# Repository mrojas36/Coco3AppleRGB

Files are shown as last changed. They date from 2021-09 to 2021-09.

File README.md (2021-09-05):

# Coco3AppleRGB

This card will interface the **Color Computer 3 RGB port** to an **AppleColor RGB Monitor (model A2M6014)**.  It was created and shared with the CoCo community.  The design is provided here for whatever purpose you would like: make for yourself, build, sell, or modify.

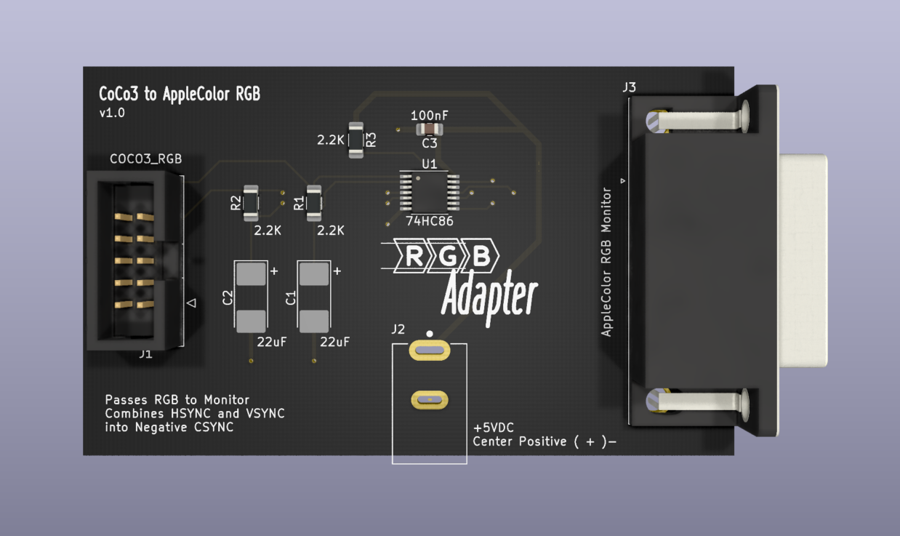
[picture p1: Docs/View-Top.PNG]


## Overview

The card was designed from an schematic from 1996 by Tomi Engdahl.  The circuit was modified to work with the AppleColor RGB Monitor. Here is the original schematic:

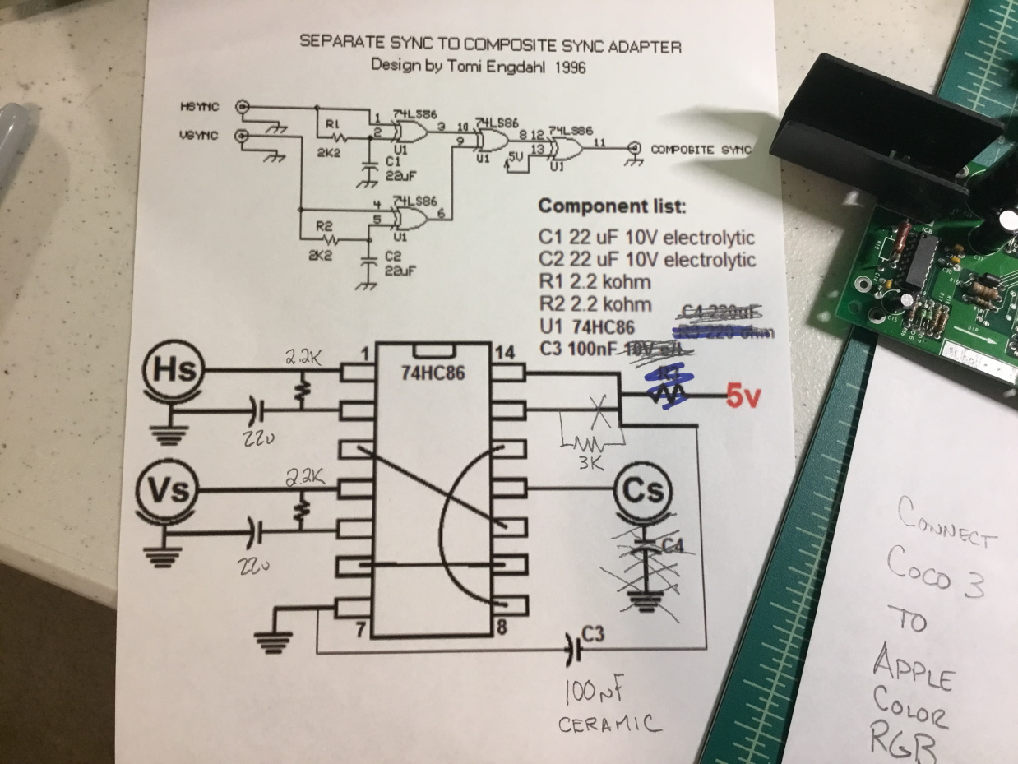
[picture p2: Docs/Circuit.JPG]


I bread boarded this circuit and made modifications (shown in pencil) to get it to work with the Apple Monitor. 

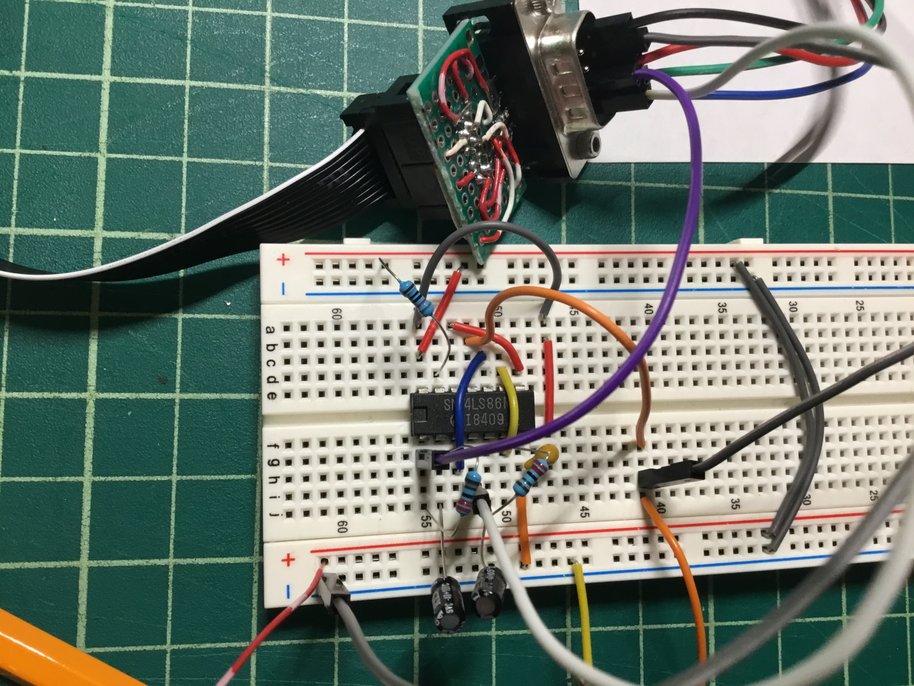
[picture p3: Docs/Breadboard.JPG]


With a bit of fiddling, I was able to achieve a display:

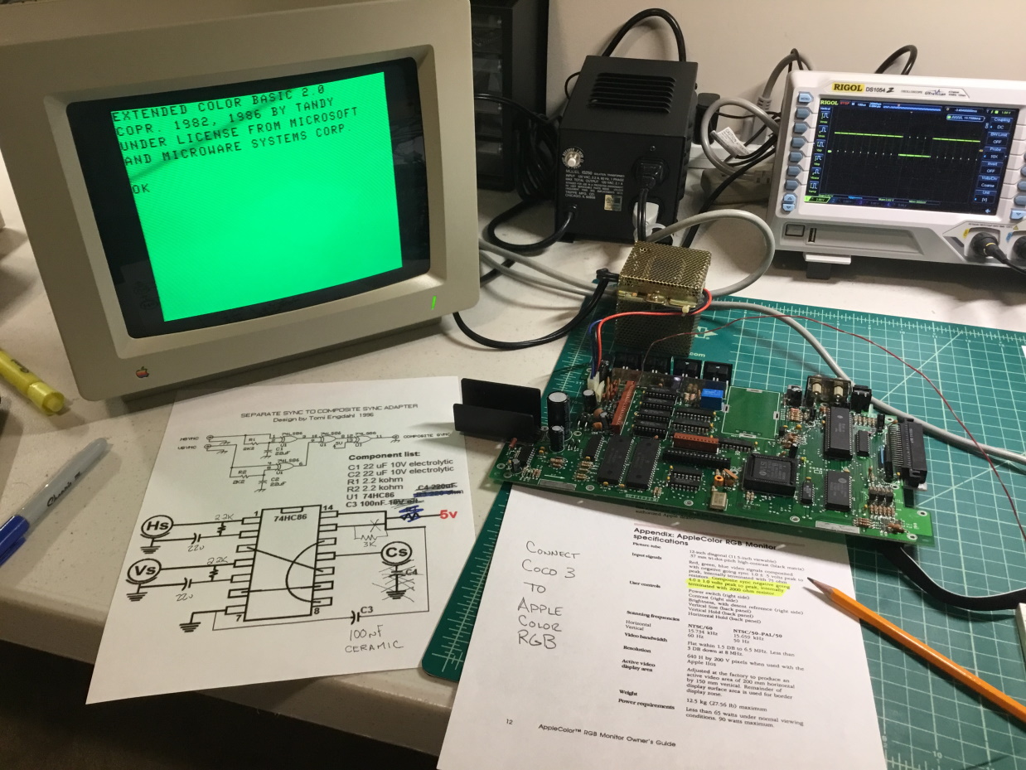
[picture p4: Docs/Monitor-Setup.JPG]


The key to getting this to work was recognizing that the Apple Monitor needs a *composite* sync (CSYNC) in order to display.  The CoCo3 has separate horizontal and vertical sync signals.  This circuit will take those signals, flip them, and then interface them into a composite signal (show on the oscilloscope).  Here is the resulting schematic:

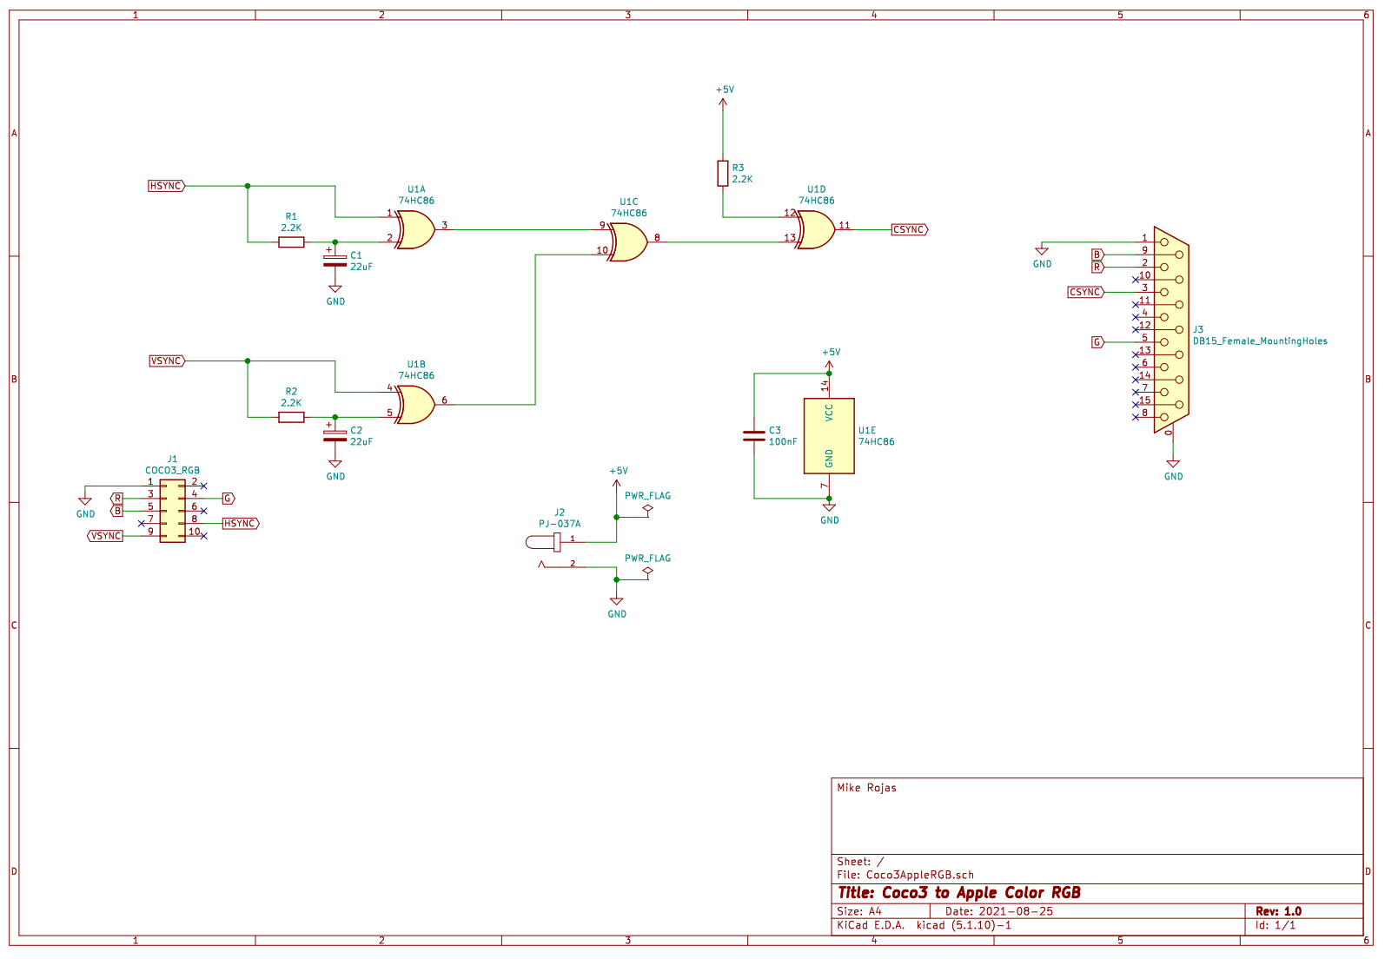
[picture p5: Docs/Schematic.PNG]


## Design

The project was built in **Kicad** and has all the project files included.  You can get a copy of Kicad from https://www.kicad.org.

Kicad was also used to layout of the PCB, show here:

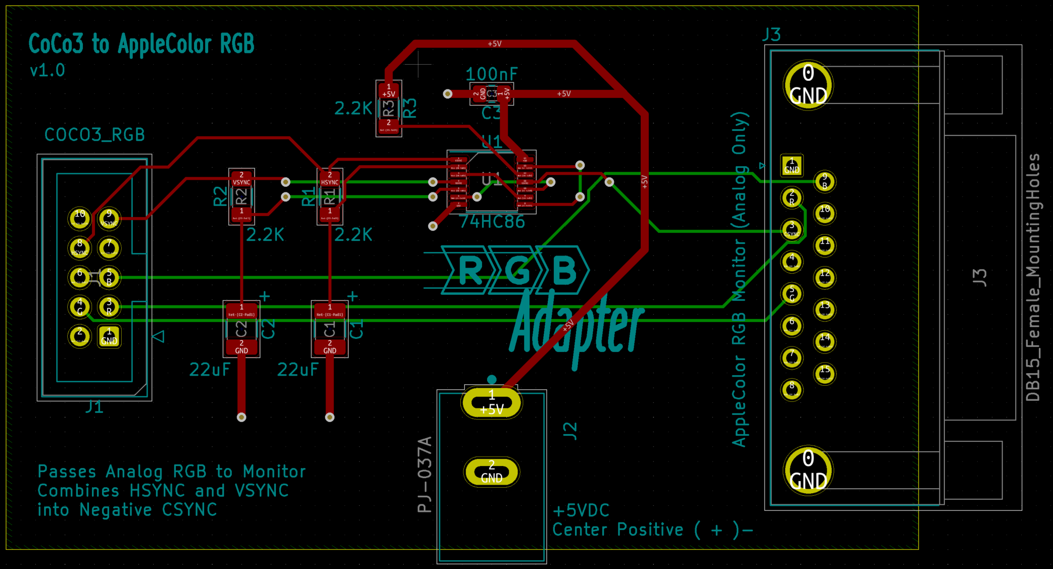
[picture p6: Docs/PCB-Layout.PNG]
PCB Layout


The bill of material is straightforward and only contains easy to find parts.  At the time of writing the total board cost is under $7 USD.

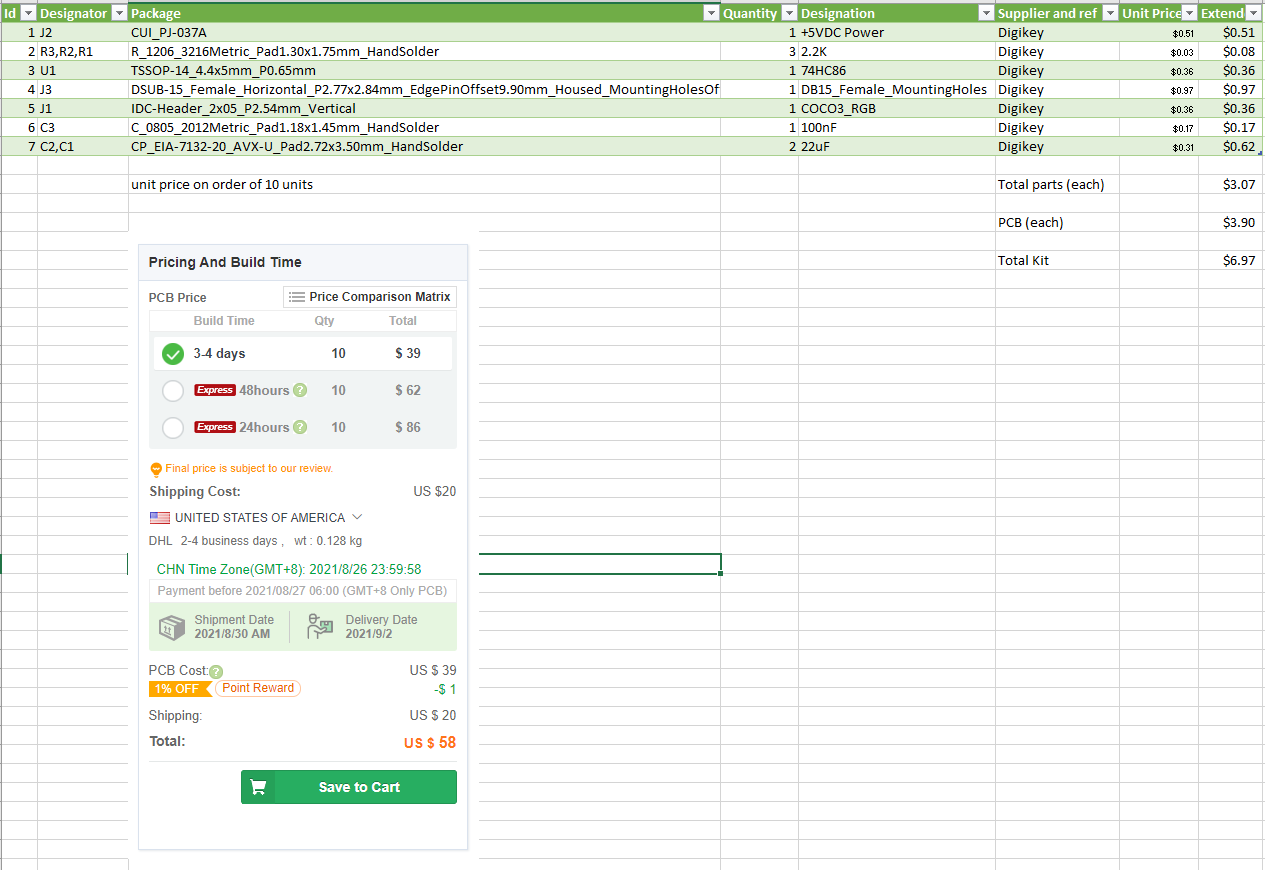
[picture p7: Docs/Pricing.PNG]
Pricing


The finished board:

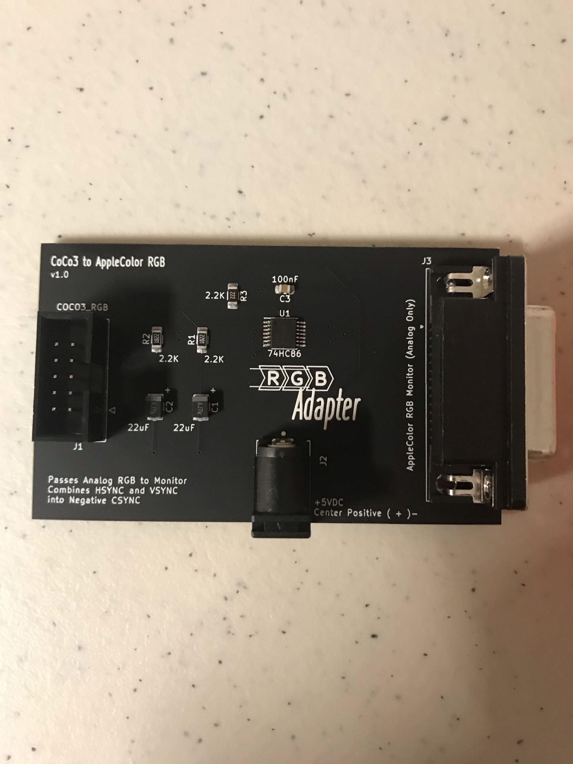
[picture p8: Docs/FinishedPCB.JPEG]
PCB


## Case

This project also contains a 3D printable case design.  The case is in two parts: Top and Bottom.  No screws are needed as the bottom slides into the top part for a snug fit.

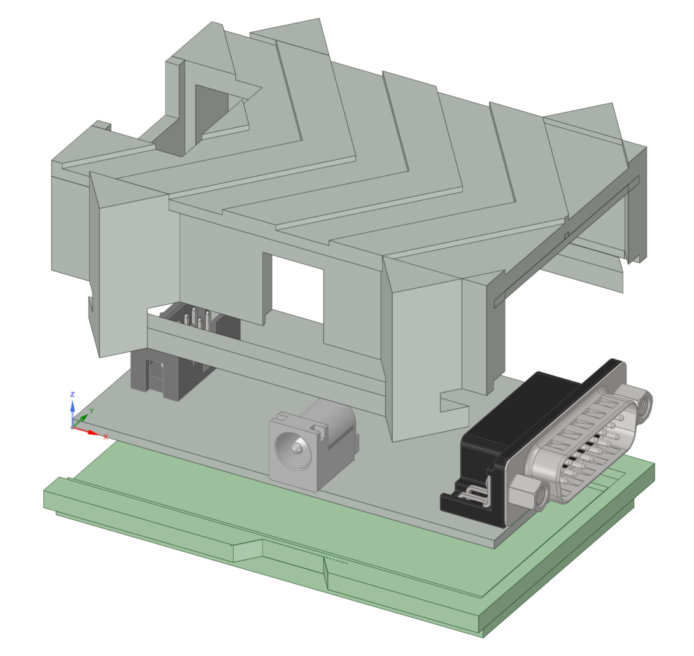
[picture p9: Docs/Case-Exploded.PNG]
Case


The case was designed using **DesignSpark Mechanical**.  This is a free design tool.  You can download the tool from https://www.rs-online.com/designspark/mechanical-software.  The design files are included in the Case folder.

Here are some photos of the finished case:

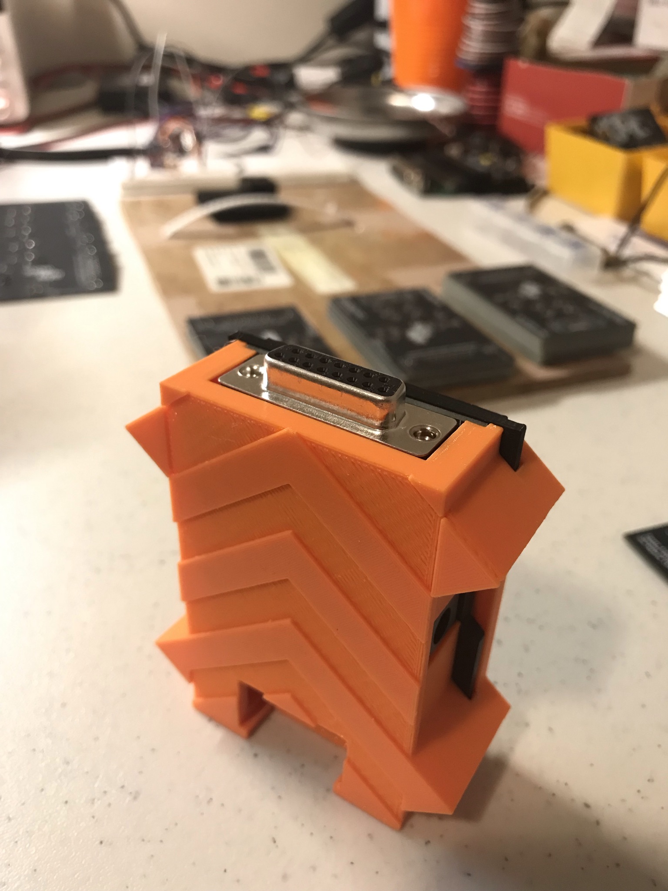
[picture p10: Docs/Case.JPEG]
Case

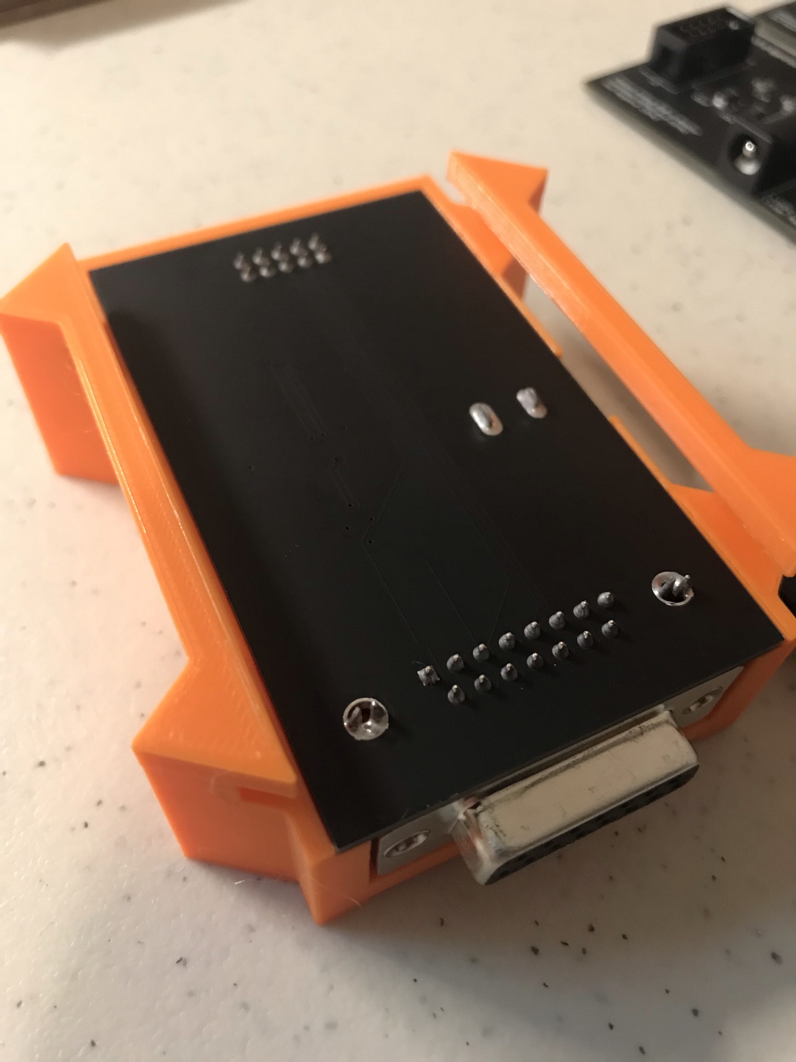
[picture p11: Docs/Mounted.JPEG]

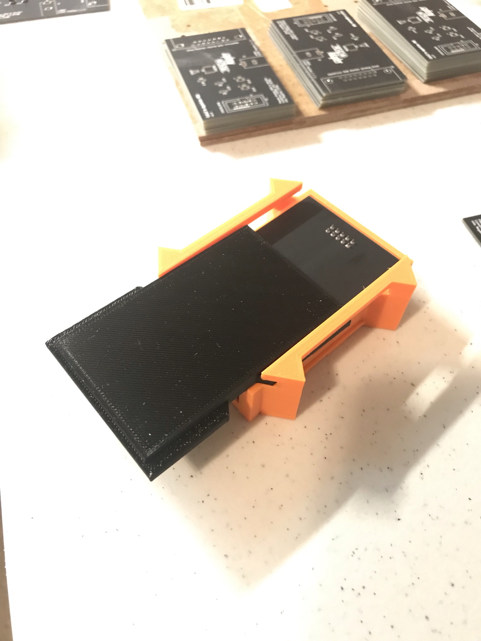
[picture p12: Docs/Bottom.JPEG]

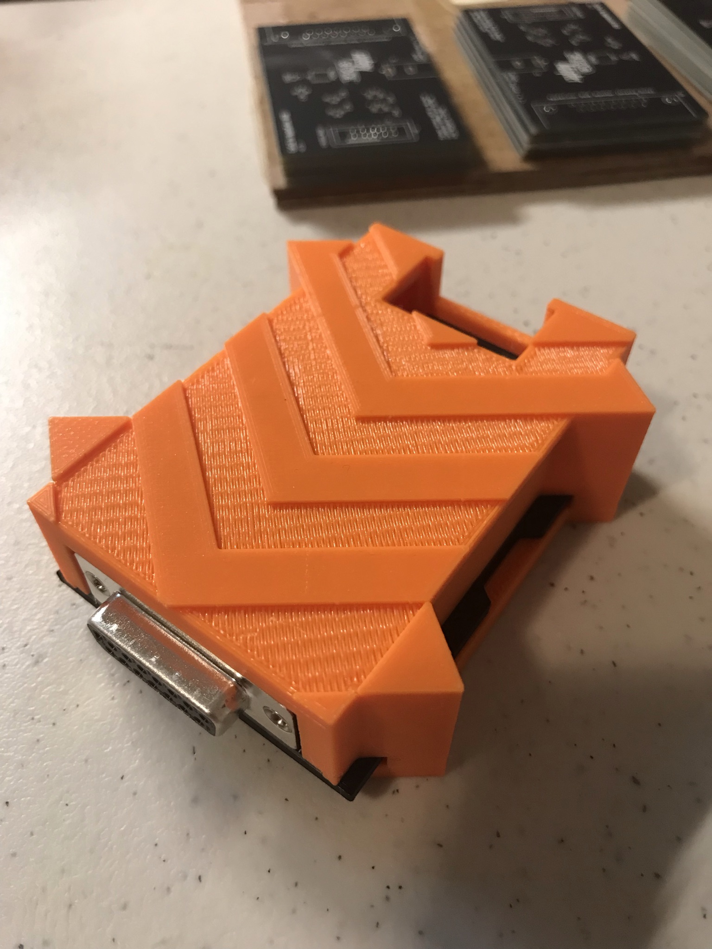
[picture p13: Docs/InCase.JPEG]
Case


## Additional Parts

The adapter works very well and 80 column text is very legible. To complete the set you will need a **5VDC Power Adaptor with a 5.5mm x 2.5mm plug, center positive**.  You will also need a **10 pin ribbon cable** to connect to the underside of the CoCo3.

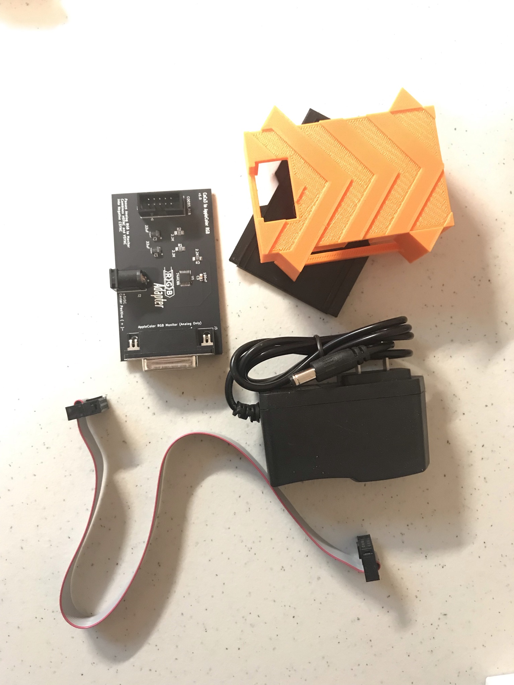
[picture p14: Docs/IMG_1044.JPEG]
Set

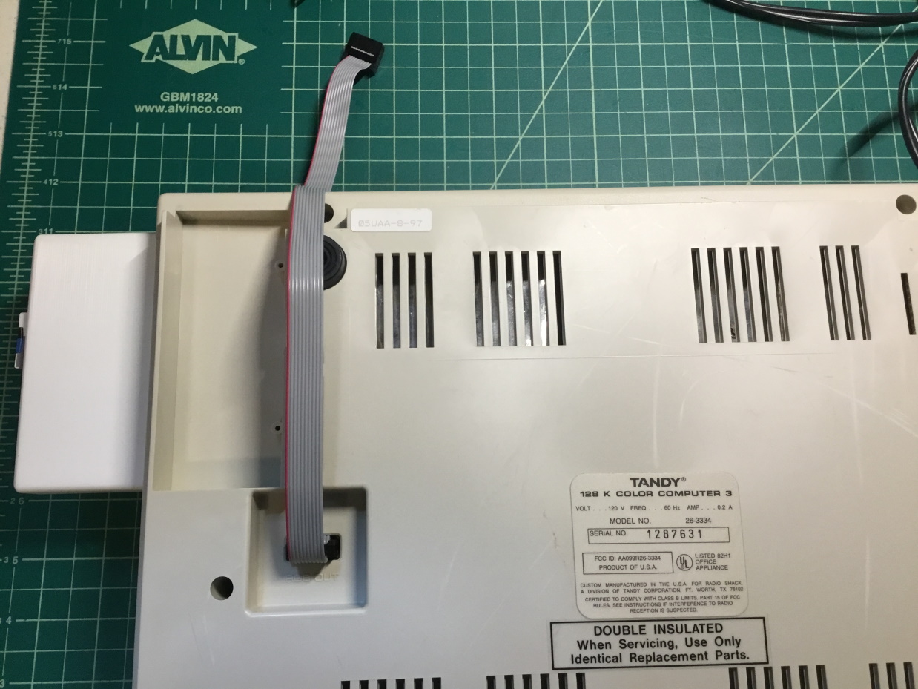
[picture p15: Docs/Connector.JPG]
Connector

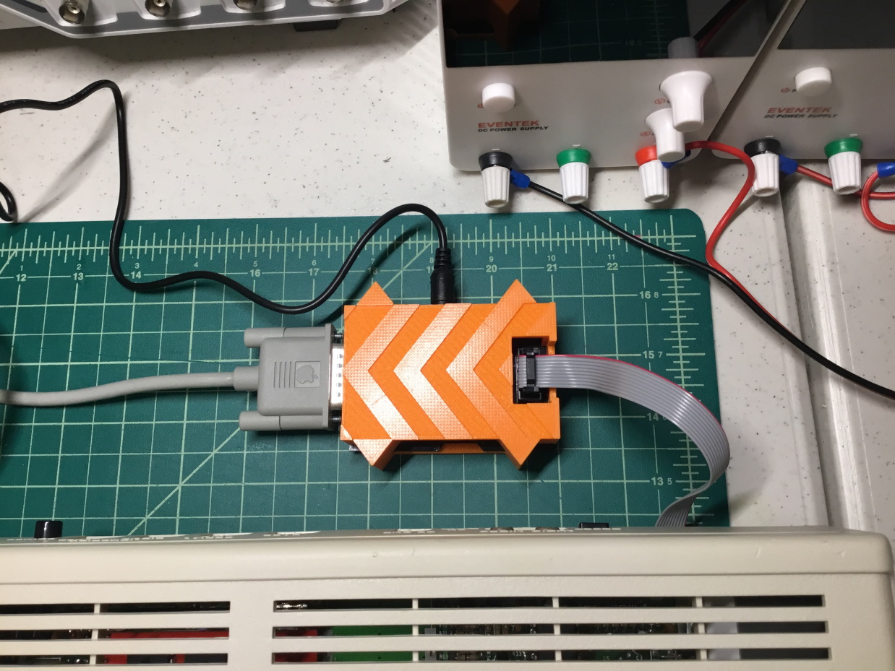
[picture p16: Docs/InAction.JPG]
CoCo3


## Complete - Enjoy!

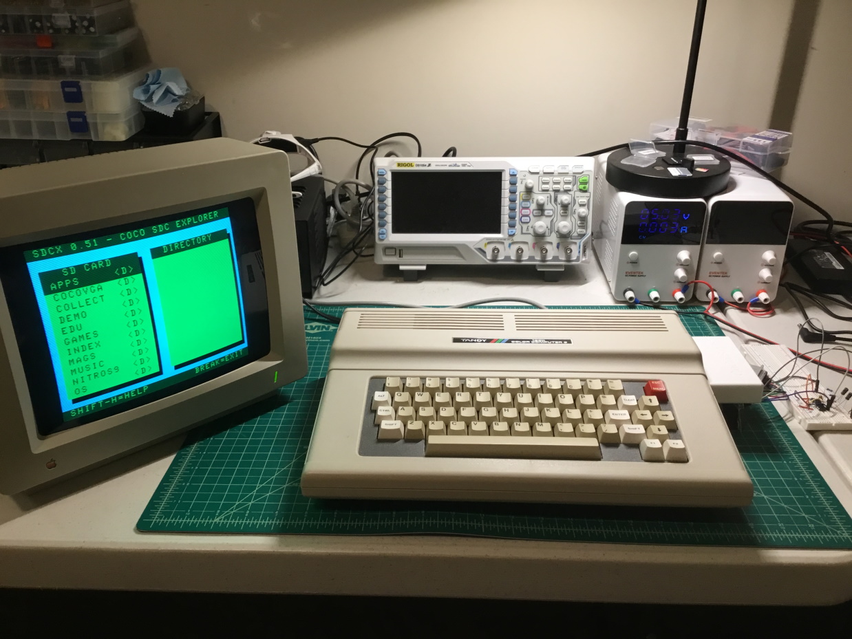
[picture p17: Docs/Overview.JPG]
Overview


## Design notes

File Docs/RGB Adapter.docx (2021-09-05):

# RGB Adapter (CoCo3 to AppleColor RGB)

# Overview

The CoCo3 is an amazing machine, but it is not known for having great RF and Composite video output. A preferred route is to use the RGB port on the bottom of the machine to display GIME’s video on an Analog RGB Monitor. The result is a much clearer and crisper picture.

The GIME chip has separate signals for the two video formats, CVIDEO, and RGB Video. You can see the pins on the chip here:

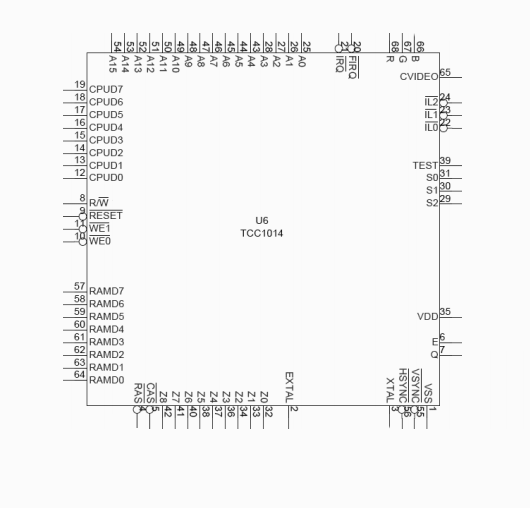
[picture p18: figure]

The CVIDEO line carries all the video data and synchronization information in one signal. The RGB video on the other hand, requires the use of two additional signals used for synchronization: HSYNC and VSYNC. These two signals tell the monitor when a video line starts (HSYNC) and when the page frame begins (VSYNC).

Here are the two signals in action. The top signal is HSYNC and the bottom signal is VSYNC. Notice how the top signal is pulse much more rapidly than the bottom signal. That is because the top signal is pulsed for every line drawn and bottom is once per page.

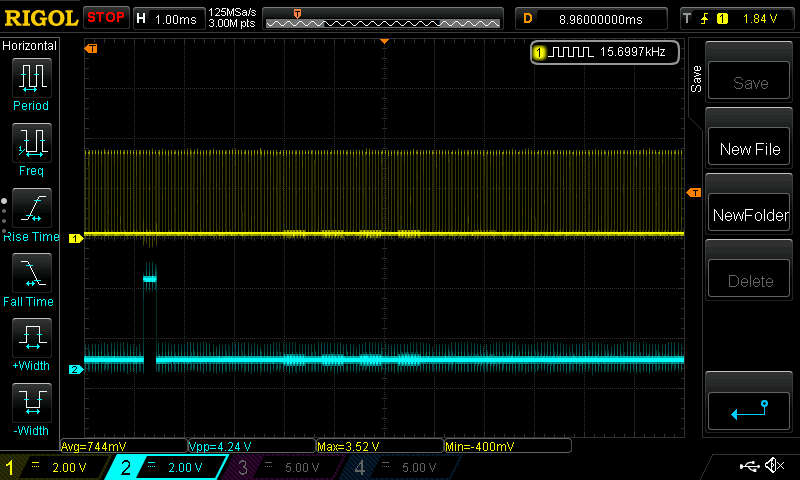
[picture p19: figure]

HSYNC

VSYNC

# Apple RGB Monitor

The AppleColor RGB monitor for the IIgs is an analog monitor. The RGB signals vary in amplitude and that indicates the intensity of that color. For example, full voltage on the G signal would mean the brightest green, and no voltage on the G signal would mean no green at all.

The RGB signals coming out of the CoCo3 match this format and are compatible with the monitor. However, the video synchronization signals are not.

The Apple monitor requires the both the HSYNC and the VSYNC to be in the same signal. In addition, the monitor requires the signals to be active low. This means they will remain at a high voltage level and then drop to a low level when triggered. This means the monitor needs the signals to be inverted from what the CoCo3 provides.

# Composite Sync (CSYNC)

A composite video sync signal looks very different:

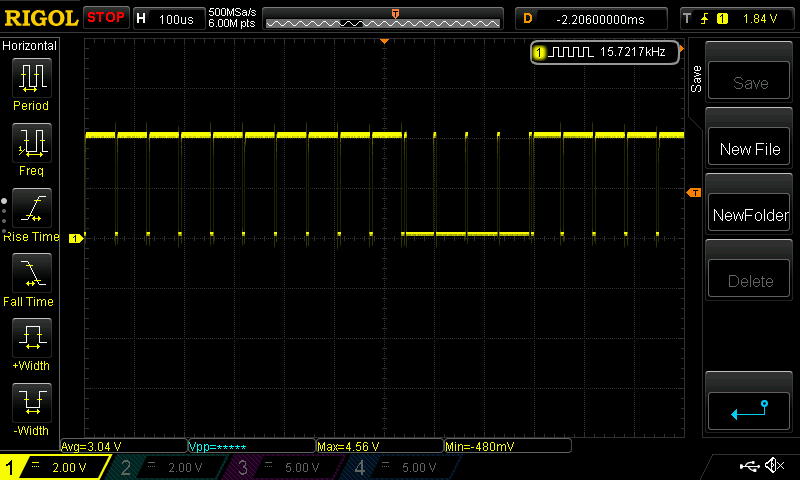
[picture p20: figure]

Here you can see the HSYNC pulses go from high to low very frequently with the VSYNC going to low voltage when it is active. During that time, the HSYNC reverses direction and goes from low to high.

Very complicated.

Fortunately, we can accomplish this transformation with four XOR logic gates, arranged like this:

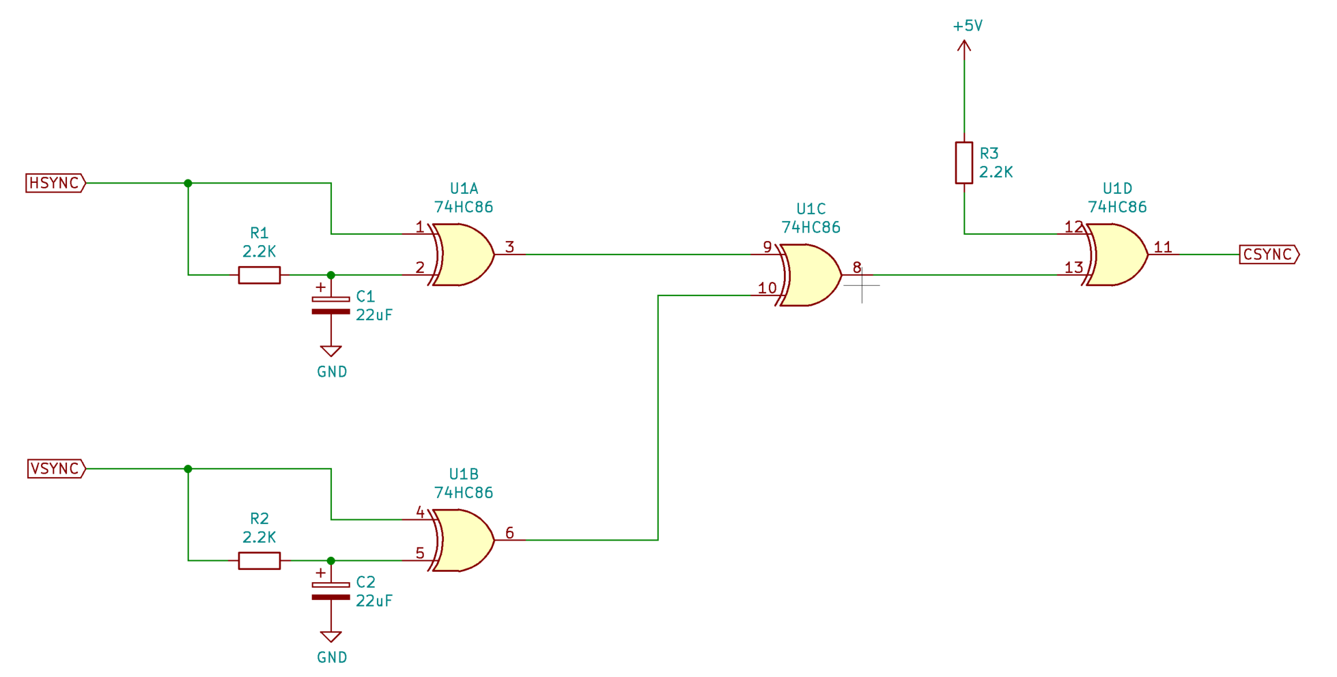
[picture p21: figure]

# Adapter Board

The board is a small card measuring 79mm x 49mm and contains all the electronics to convert the HSYNC and VSYNC to CSYNC. The CoCo3’s RGB signals are passed through to the monitor untouched.

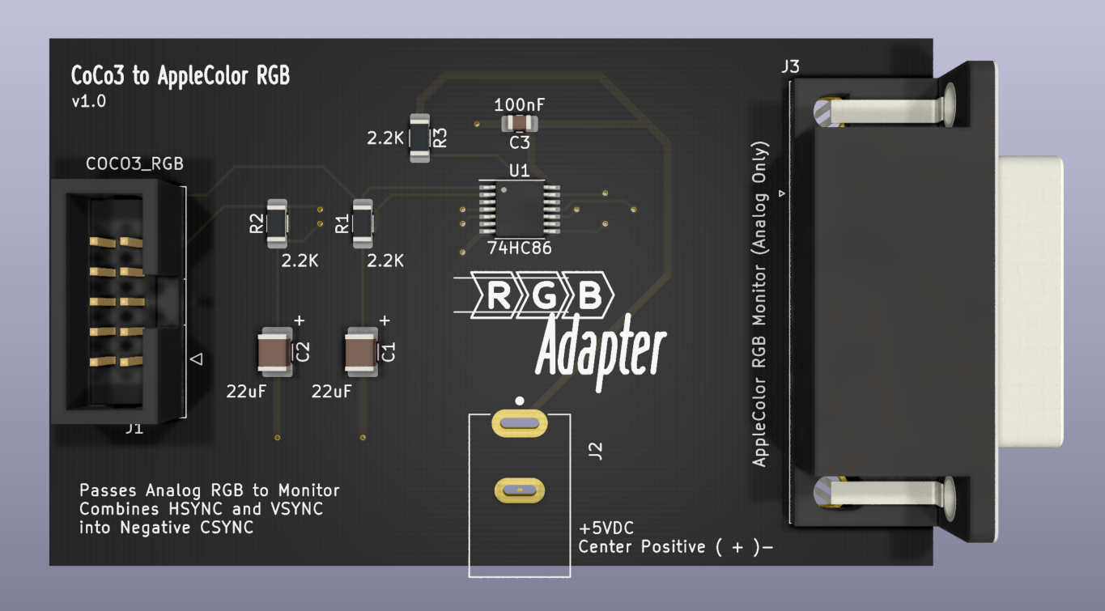
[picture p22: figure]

The unit requires a 5VDC power supply using a DC barrel connector 5.5mm x 2.5mm plug:

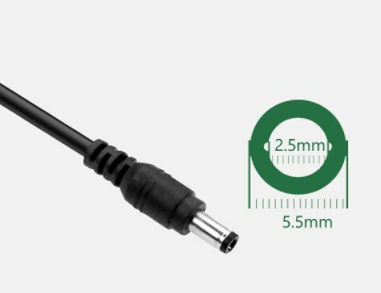
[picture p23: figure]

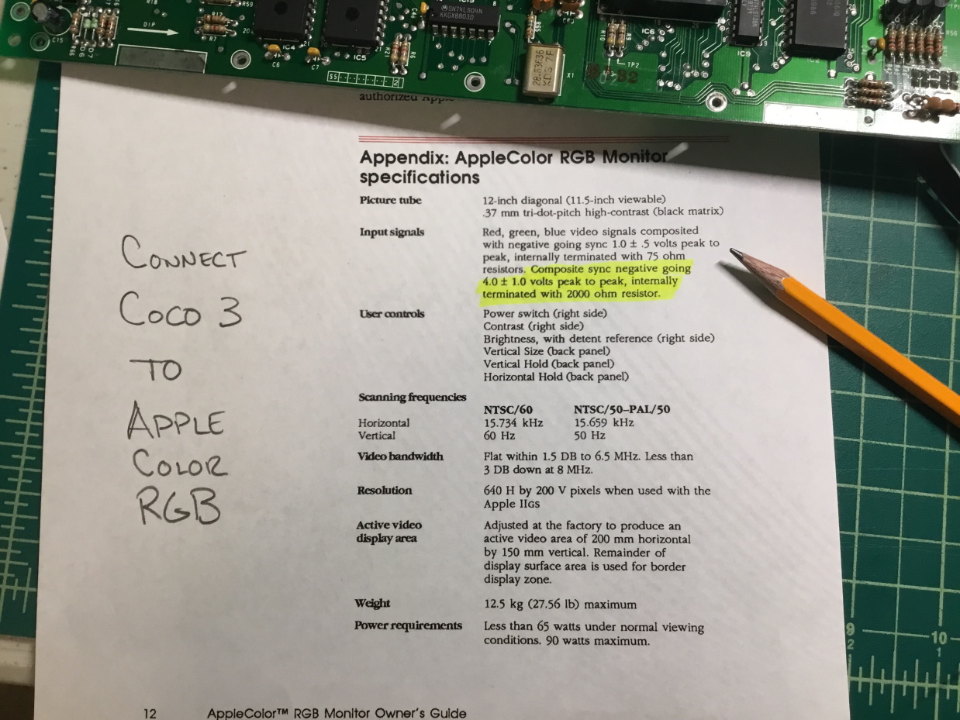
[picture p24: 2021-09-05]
Docs/MonitorSpecs.JPG

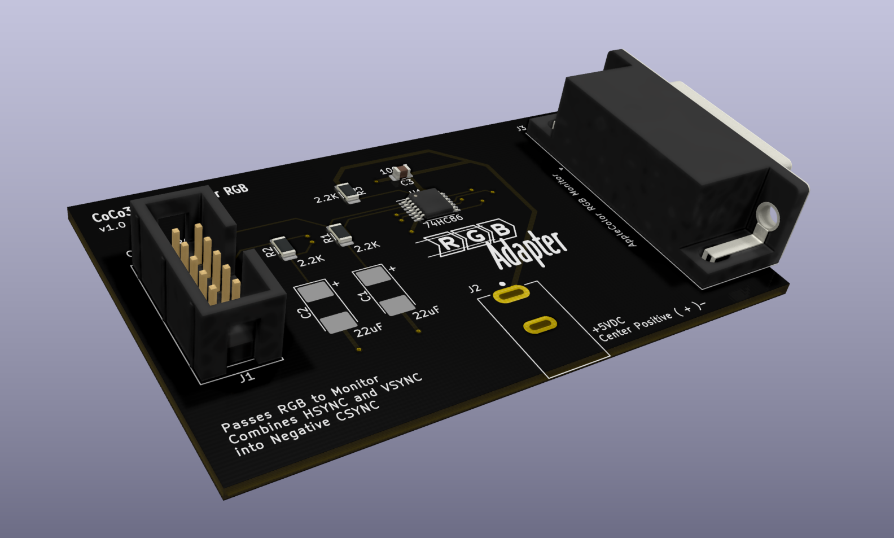
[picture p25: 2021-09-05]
Docs/View-Angle.PNG

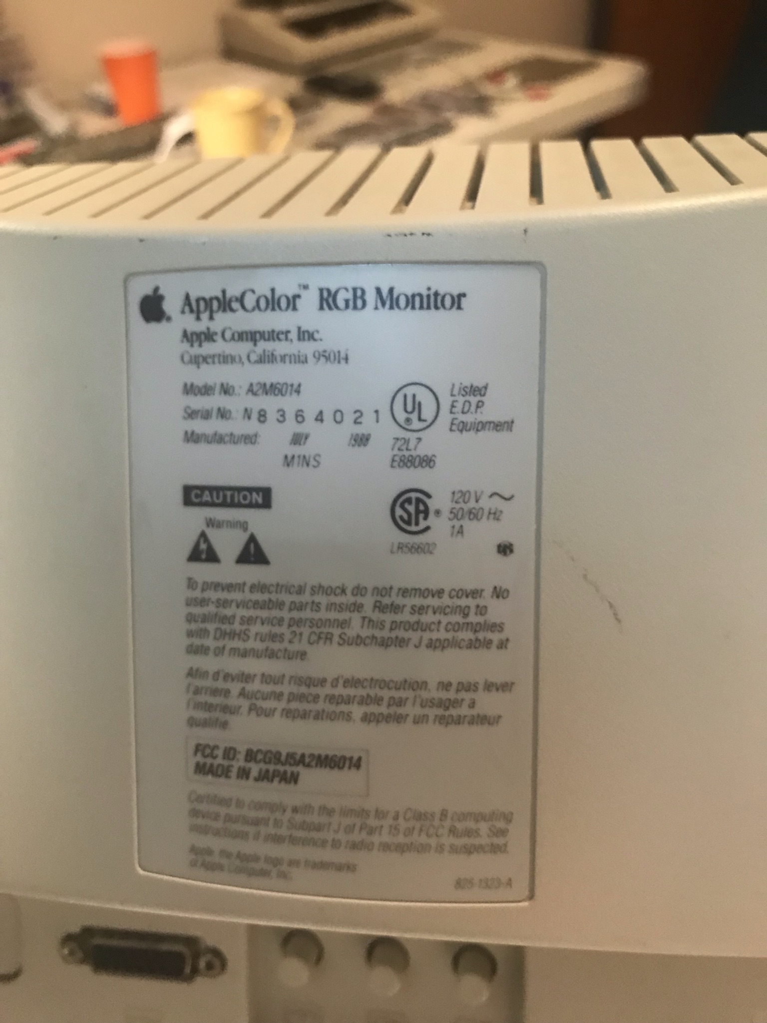
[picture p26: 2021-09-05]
Docs/MonitorModel.JPEG

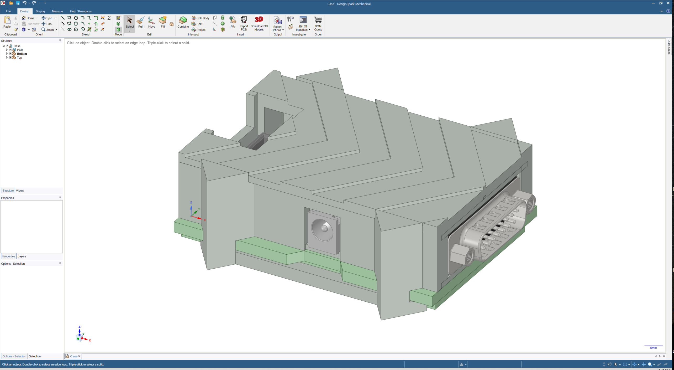
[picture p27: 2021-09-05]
Docs/Case.PNG

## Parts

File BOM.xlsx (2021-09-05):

Id | Designator | Package | Quantity | Designation | Supplier and ref | Unit Price | Extended
1 | J2 | CUI_PJ-037A | 1 | +5VDC Power | Digikey | $0.51 | $0.51
2 | R3,R2,R1 | R_1206_3216Metric_Pad1.30x1.75mm_HandSolder | 3 | 2.2K | Digikey | $0.03 | $0.08
3 | U1 | TSSOP-14_4.4x5mm_P0.65mm | 1 | 74HC86 | Digikey | $0.36 | $0.36
4 | J3 | DSUB-15_Female_Horizontal_P2.77x2.84mm_EdgePinOffset9.90mm_Housed_MountingHolesOffset11.32mm | 1 | DB15_Female_MountingHoles | Digikey | $0.97 | $0.97
5 | J1 | IDC-Header_2x05_P2.54mm_Vertical | 1 | COCO3_RGB | Digikey | $0.36 | $0.36
6 | C3 | C_0805_2012Metric_Pad1.18x1.45mm_HandSolder | 1 | 100nF | Digikey | $0.17 | $0.17
7 | C2,C1 | CP_EIA-7132-20_AVX-U_Pad2.72x3.50mm_HandSolder | 2 | 22uF | Digikey | $0.31 | $0.62
 |  | unit price on order of 10 units |  |  | Total parts (each) |  | $3.07
 |  |  |  |  | PCB (each) |  | $3.90
 |  |  |  |  | Total Kit |  | $6.97

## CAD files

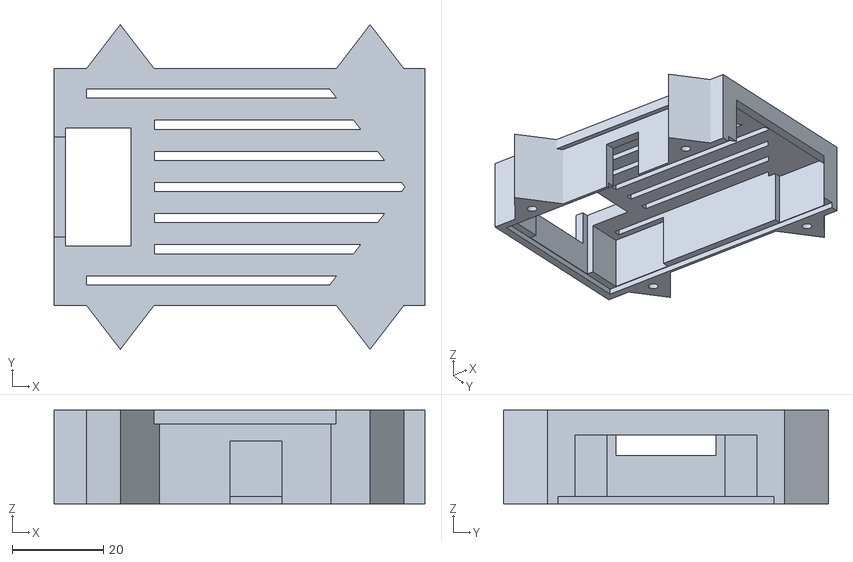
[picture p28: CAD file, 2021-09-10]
Case/Case2.stl
81.5 x 71.3 x 20.6

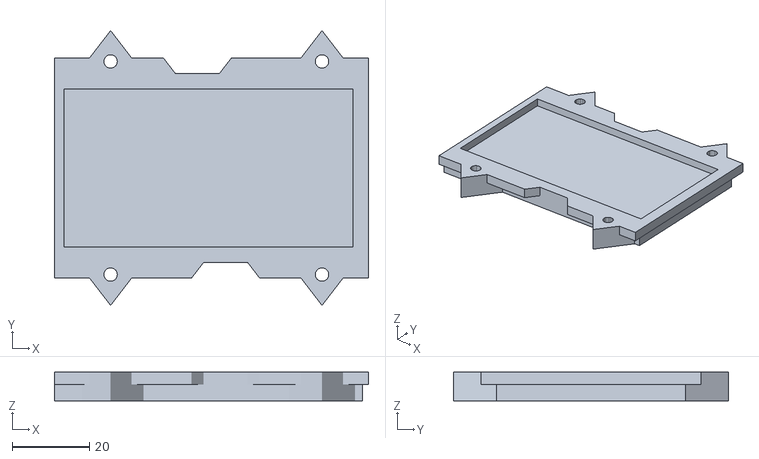
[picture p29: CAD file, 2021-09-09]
Case/Case2-Bottom.stl
81.5 x 71.3 x 7.40

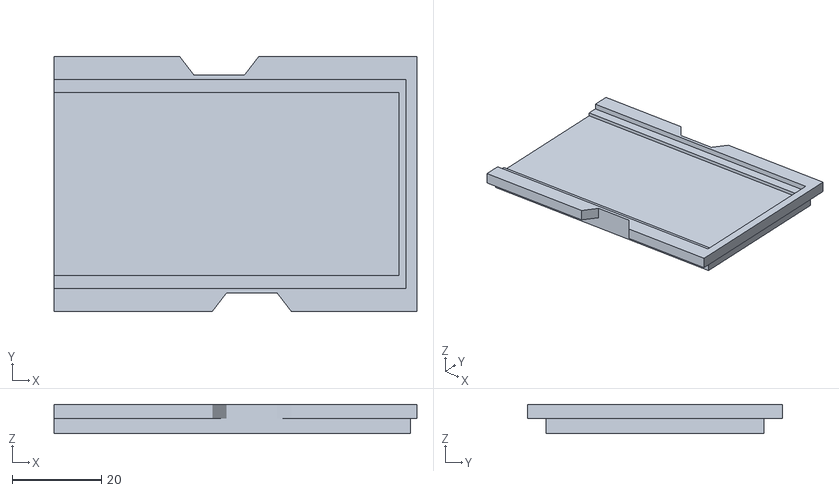
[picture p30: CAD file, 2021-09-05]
Case/Case-Bottom.stl
81.5 x 57.2 x 6.60

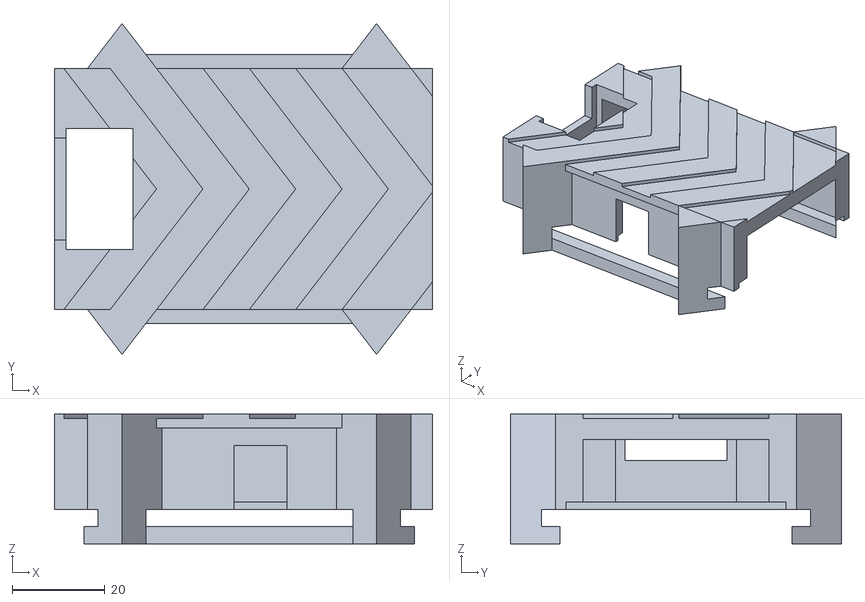
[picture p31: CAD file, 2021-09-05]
Case/Case.stl
81.5 x 71.3 x 28.0

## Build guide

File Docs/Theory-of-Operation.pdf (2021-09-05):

# RGB Adapter (CoCo3 to AppleColor RGB)

## Overview

The CoCo3 is an amazing machine, but it is not known for having great RF and Composite video output. A preferred route is to use the RGB port on the bottom of the machine to display GIME’s video on an Analog RGB Monitor. The result is a much clearer and crisper picture.

The GIME chip has separate signals for the two video formats, CVIDEO, and RGB Video. You can see the pins on the chip here:

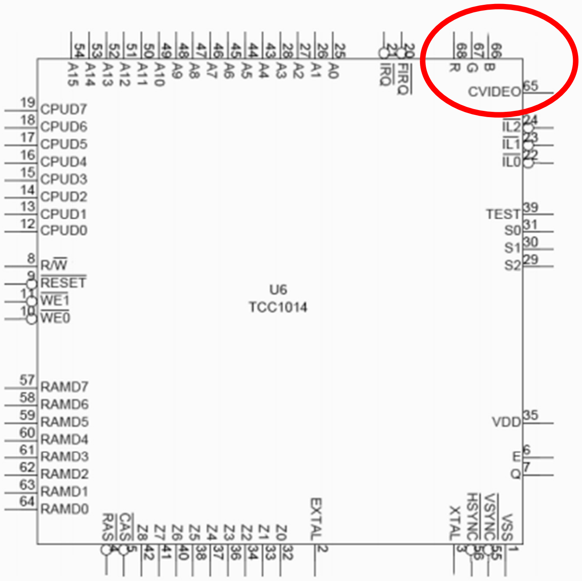
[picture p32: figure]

The CVIDEO line carries all the video data and synchronization information in one signal. The RGB video on the other hand, requires the use of two additional signals used for synchronization: HSYNC and VSYNC. These two signals tell the monitor when a video line starts (HSYNC) and when the page frame begins (VSYNC).

Here are the two signals in action. The top signal is HSYNC and the bottom signal is VSYNC. Notice how the top signal is pulse much more rapidly than the bottom signal. That is because the top signal is pulsed for every line drawn and bottom is once per page.

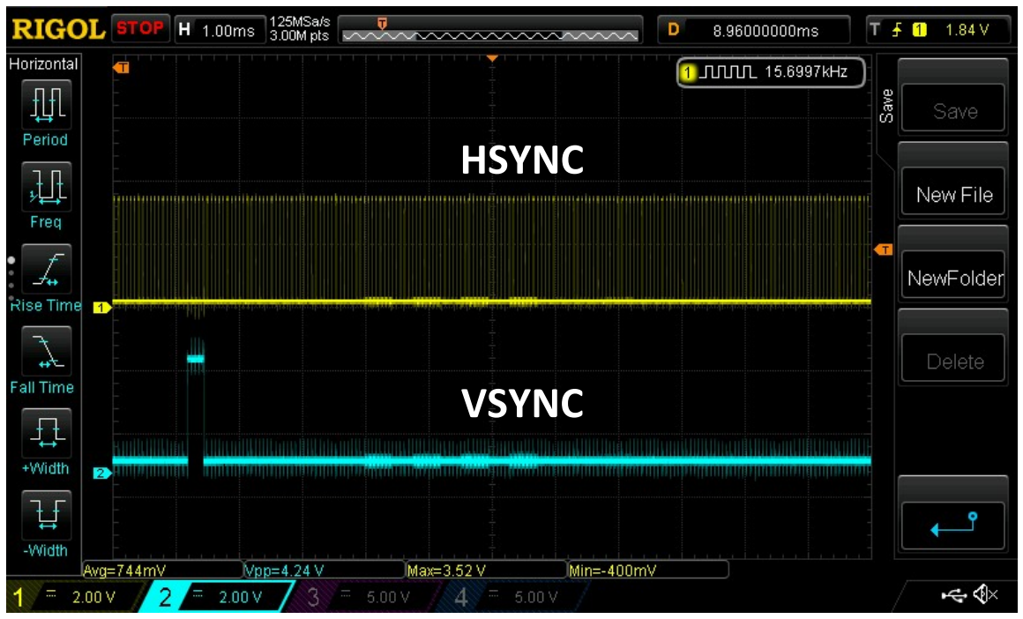
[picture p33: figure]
HSYNC; VSYNC

## Apple RGB Monitor

The AppleColor RGB monitor for the IIgs is an analog monitor. The RGB signals vary in amplitude and that indicates the intensity of that color. For example, full voltage on the G signal would mean the brightest green, and no voltage on the G signal would mean no green at all.
The RGB signals coming out of the CoCo3 match this format and are compatible with the monitor. However, the video synchronization signals are not.
The Apple monitor requires the both the HSYNC and the VSYNC to be in the same signal. In addition, the monitor requires the signals to be active low. This means they will remain at a high voltage level and then drop to a low level when triggered. This means the monitor needs the signals to be inverted from what the CoCo3 provides.

## Composite Sync (CSYNC)

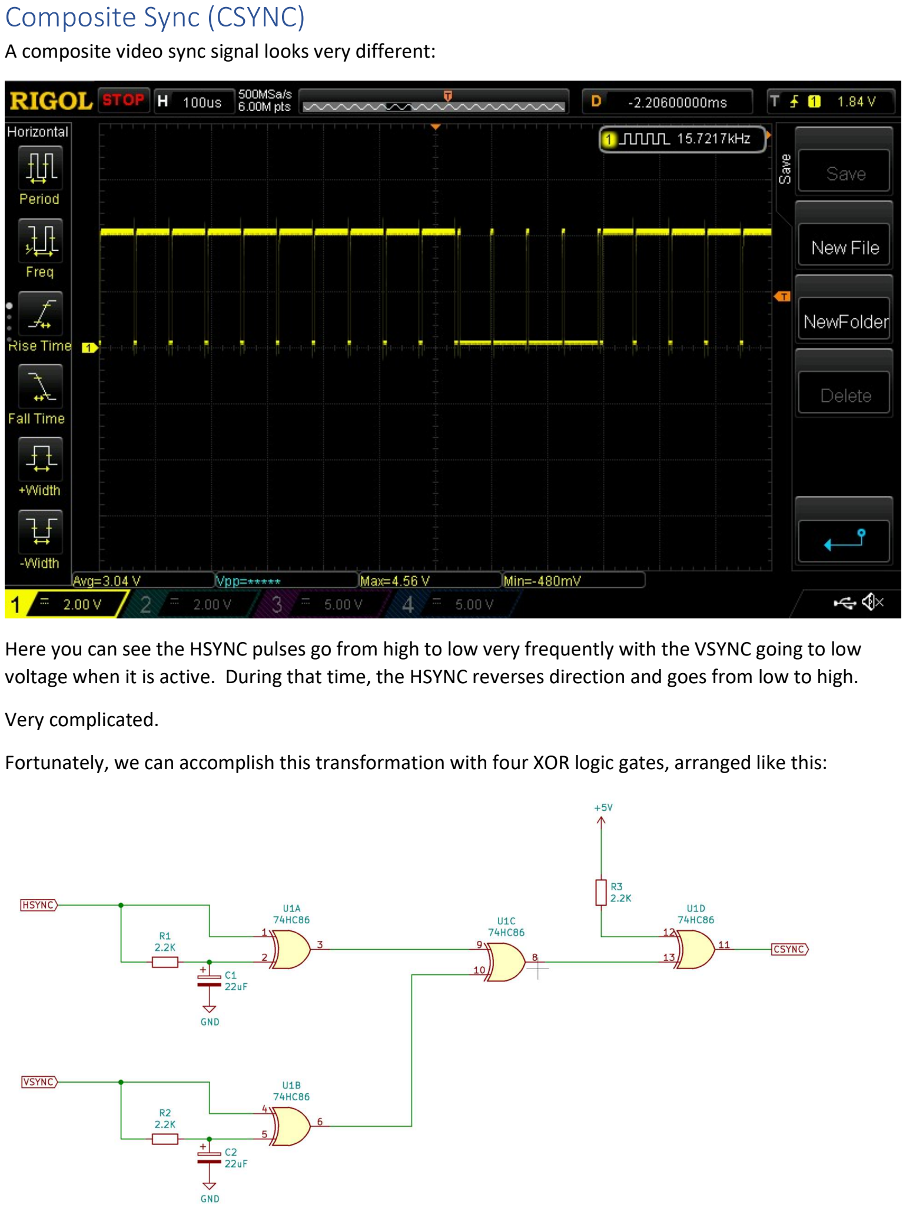
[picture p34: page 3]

A composite video sync signal looks very different:

Here you can see the HSYNC pulses go from high to low very frequently with the VSYNC going to low voltage when it is active. During that time, the HSYNC reverses direction and goes from low to high. Very complicated.
Fortunately, we can accomplish this transformation with four XOR logic gates, arranged like this:

## Adapter Board

The board is a small card measuring 79mm x 49mm and contains all the electronics to convert the HSYNC and VSYNC to CSYNC. The CoCo3’s RGB signals are passed through to the monitor untouched.

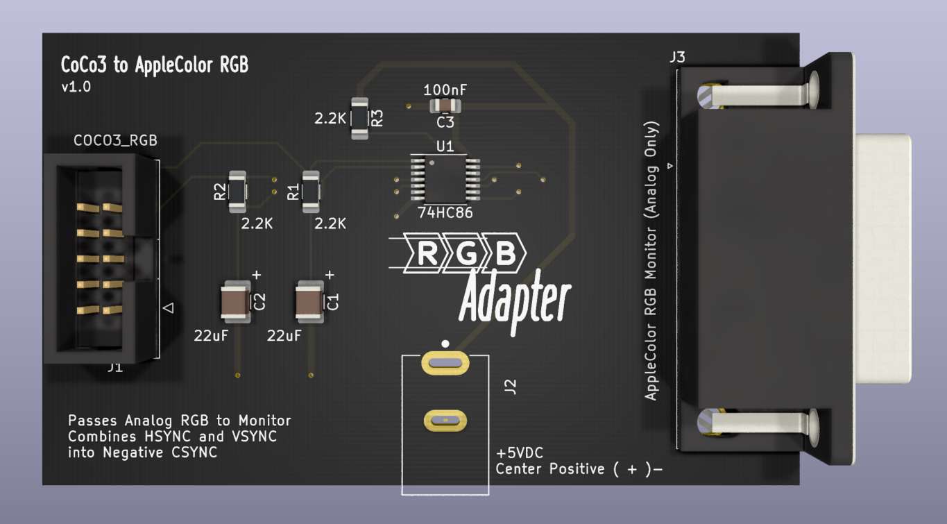
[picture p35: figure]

The unit requires a 5VDC power supply using a DC barrel connector 5.5mm x 2.5mm plug:

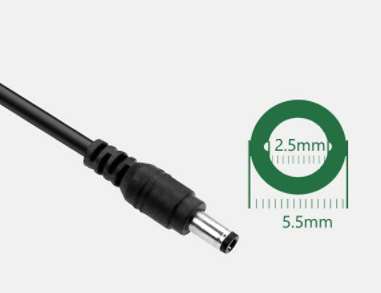
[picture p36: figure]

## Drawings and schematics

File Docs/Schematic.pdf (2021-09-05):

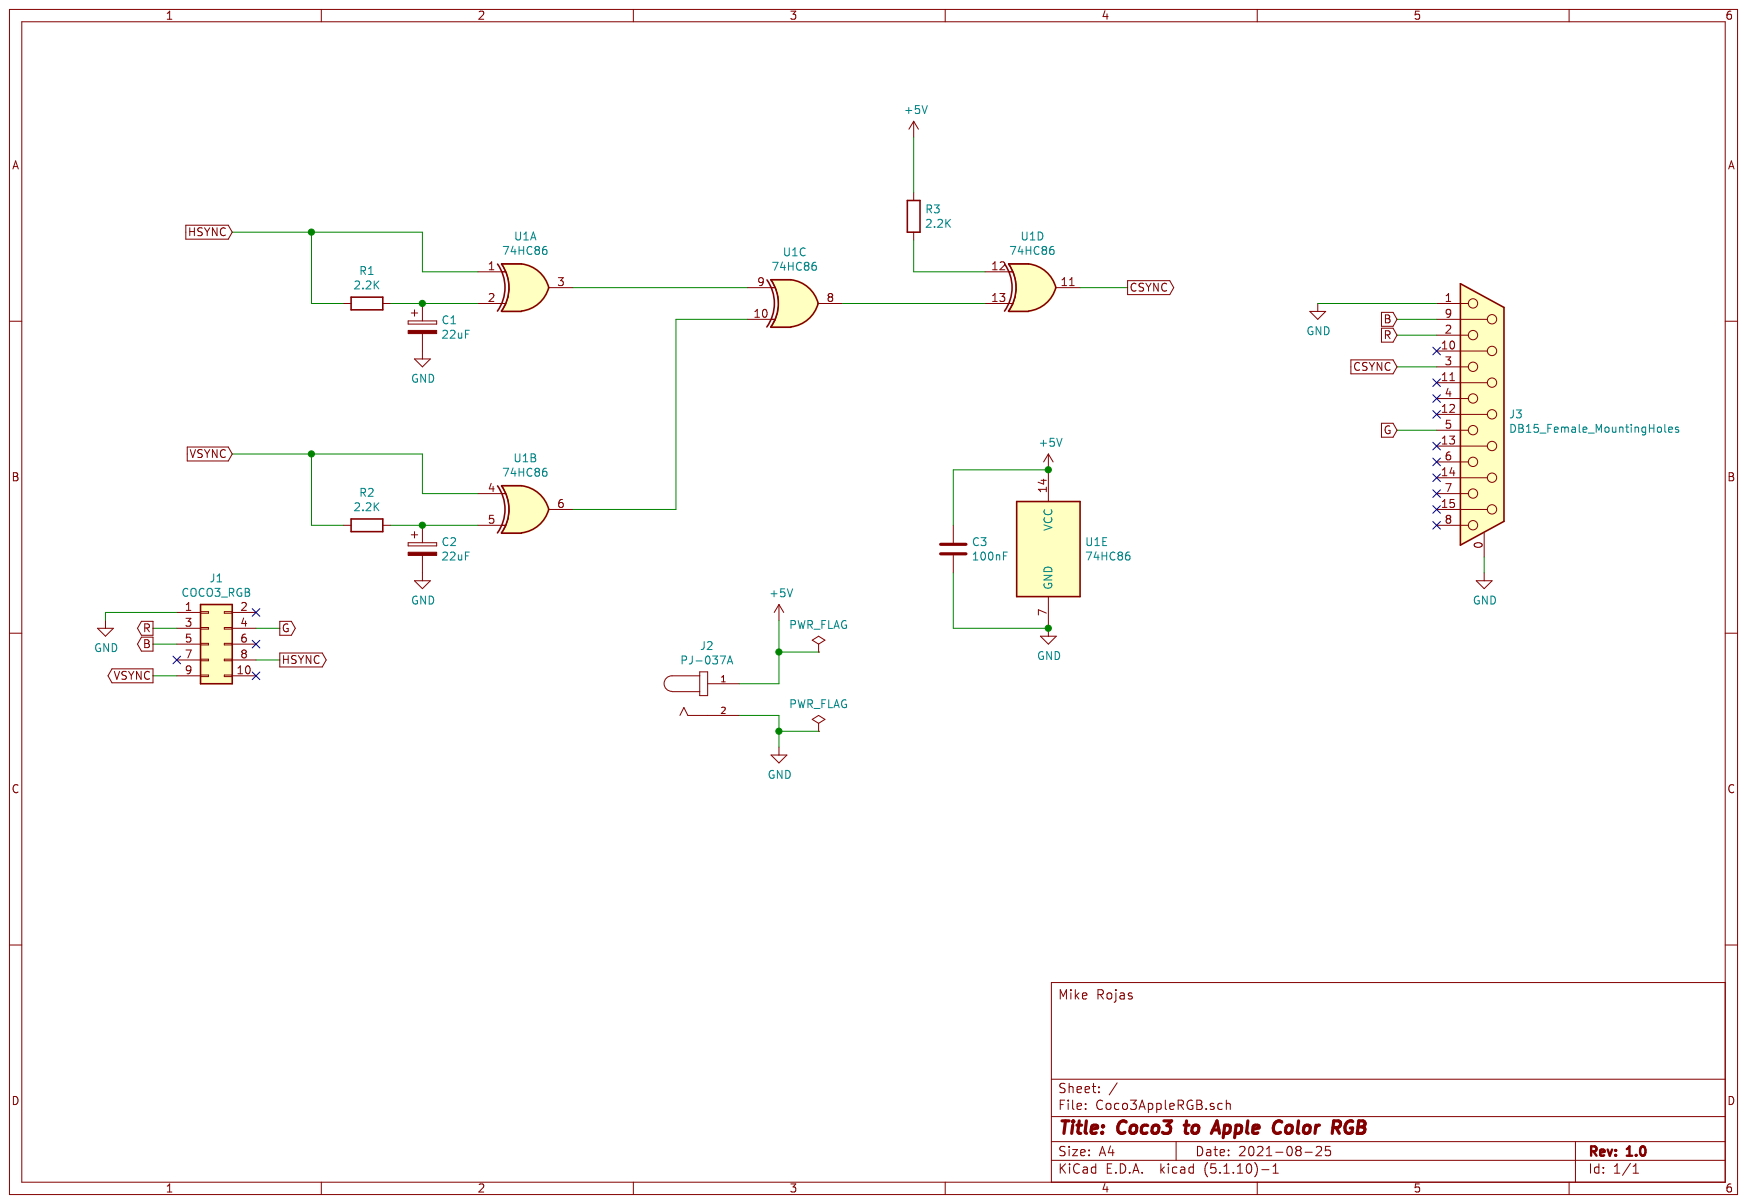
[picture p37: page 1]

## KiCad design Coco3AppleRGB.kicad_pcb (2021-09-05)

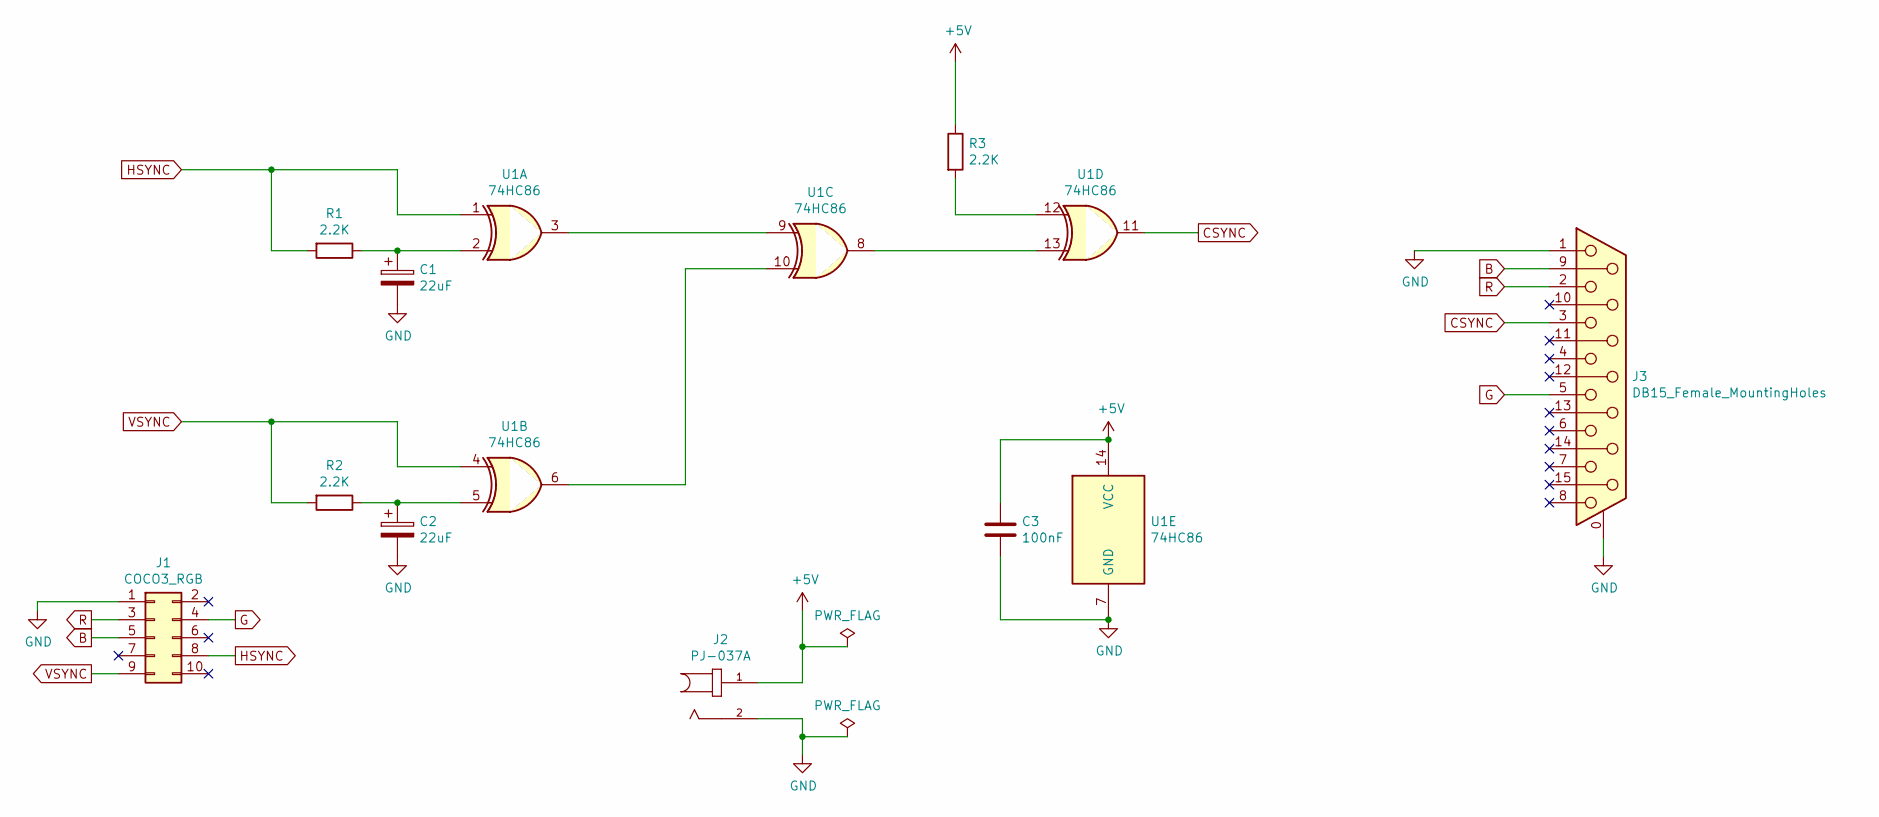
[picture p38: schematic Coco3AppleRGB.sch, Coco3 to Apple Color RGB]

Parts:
C1, C2: 22uF; C_1210_3225Metric_Pad1.33x2.70mm_HandSolder
C3: 100nF; C_0805_2012Metric_Pad1.18x1.45mm_HandSolder
J1: COCO3_RGB; IDC-Header_2x05_P2.54mm_Vertical
J2: PJ-037A; CUI_PJ-037A
J3: DB15_Female_MountingHoles; DSUB-15_Female_Horizontal_P2.77x2.84mm_EdgePinOffset9.90mm_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
R1, R2, R3: 2.2K; R_1206_3216Metric_Pad1.30x1.75mm_HandSolder
U1: 74HC86; TSSOP-14_4.4x5mm_P0.65mm

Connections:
+5V: C3.1, J2.1, R3.1, U1.14 (VCC)
B: J1.5, J3.9
CSYNC: J3.3, U1.11
G: J1.4, J3.5
GND: C1.2, C2.2, C3.2, J1.1, J2.2, J3.0 (PAD), J3.1, U1.7 (GND)
HSYNC: J1.8, R1.2, U1.1
unnamed: C1.1, R1.1, U1.2
unnamed: C2.1, R2.1, U1.5
unnamed: R3.2, U1.12
unnamed: U1.3, U1.9
unnamed: U1.6, U1.10
unnamed: U1.8, U1.13
R: J1.3, J3.2
VSYNC: J1.9, R2.2, U1.4

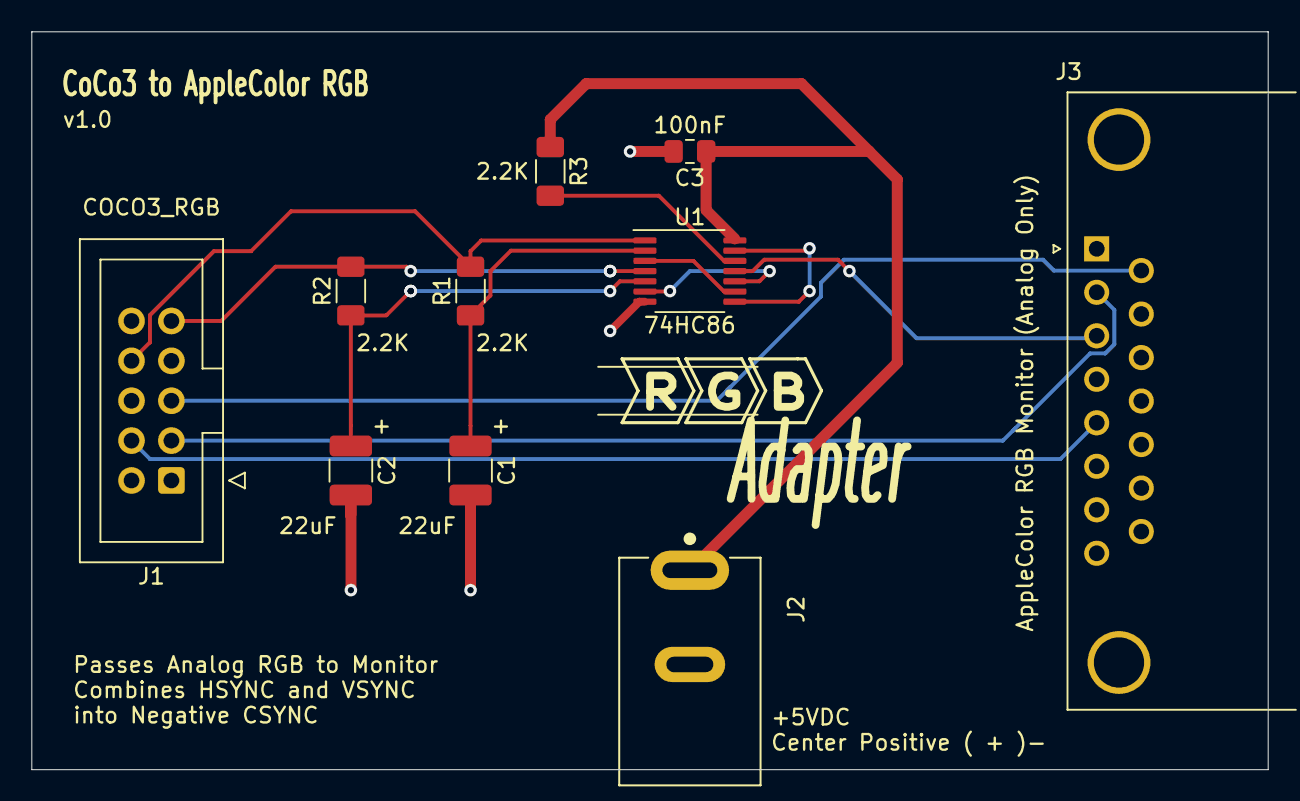
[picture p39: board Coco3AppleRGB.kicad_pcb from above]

Board: 2 copper layers, 78.7 x 47.0 mm, 10 parts (0 on the bottom side), 14 nets.

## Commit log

2021-09-09 New Case Design
    [Case2-Bottom.stl, Case2.stl]
2021-09-10 Adjusted hole size for screws
    [Case2.stl]
